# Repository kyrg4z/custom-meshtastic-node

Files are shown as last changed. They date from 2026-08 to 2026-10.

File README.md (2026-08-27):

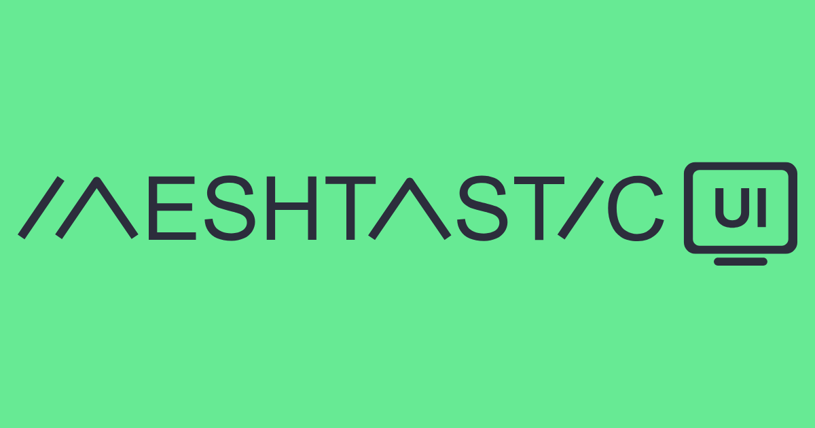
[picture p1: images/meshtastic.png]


# Custom Meshtastic/Reticulum Node 

A custom Meshtastic compatible LoRa communication device that is designed for off-grid messaging in areas where cellular/internet aren't available such as hiking trails, mountains, and forests. This device provides interface for phones to be able to send messages through long range radio through a decentralized mesh network.  

> [!NOTE]
> Read about progress status in JOURNAL.md

## Hardware Preview

Interactive KiCad viewer powered by [KiCanvas](https://kicanvas.org):

- **[Open schematic in KiCanvas](https://kicanvas.org/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)**
- **[Open PCB layout in KiCanvas](https://kicanvas.org/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)** _(board not routed yet — preview will be empty)_

A live, embedded viewer is hosted via GitHub Pages: **https://kyrg4z.github.io/custom-meshtastic-node/**

### Schematic snapshot

Schematic

<sub>Auto-exported from <code>PCB/PCB.kicad_sch</code> by <code>.githooks/pre-commit</code>. Enable it once per clone with <code>git config core.hooksPath .githooks</code>.</sub>

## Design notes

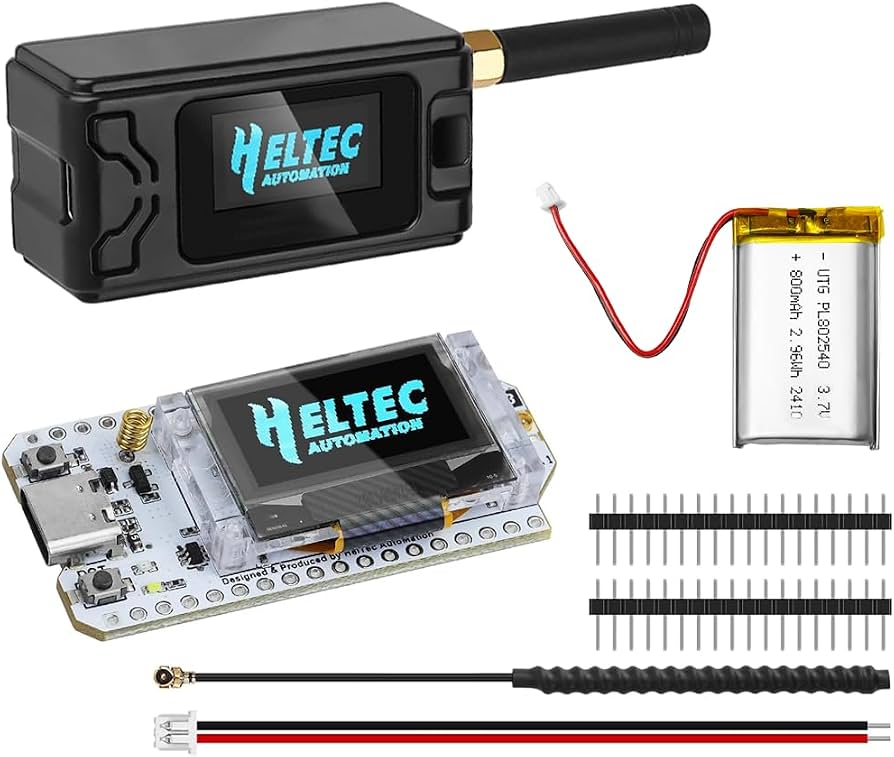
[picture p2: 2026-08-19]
images/heltec-v3.jpg

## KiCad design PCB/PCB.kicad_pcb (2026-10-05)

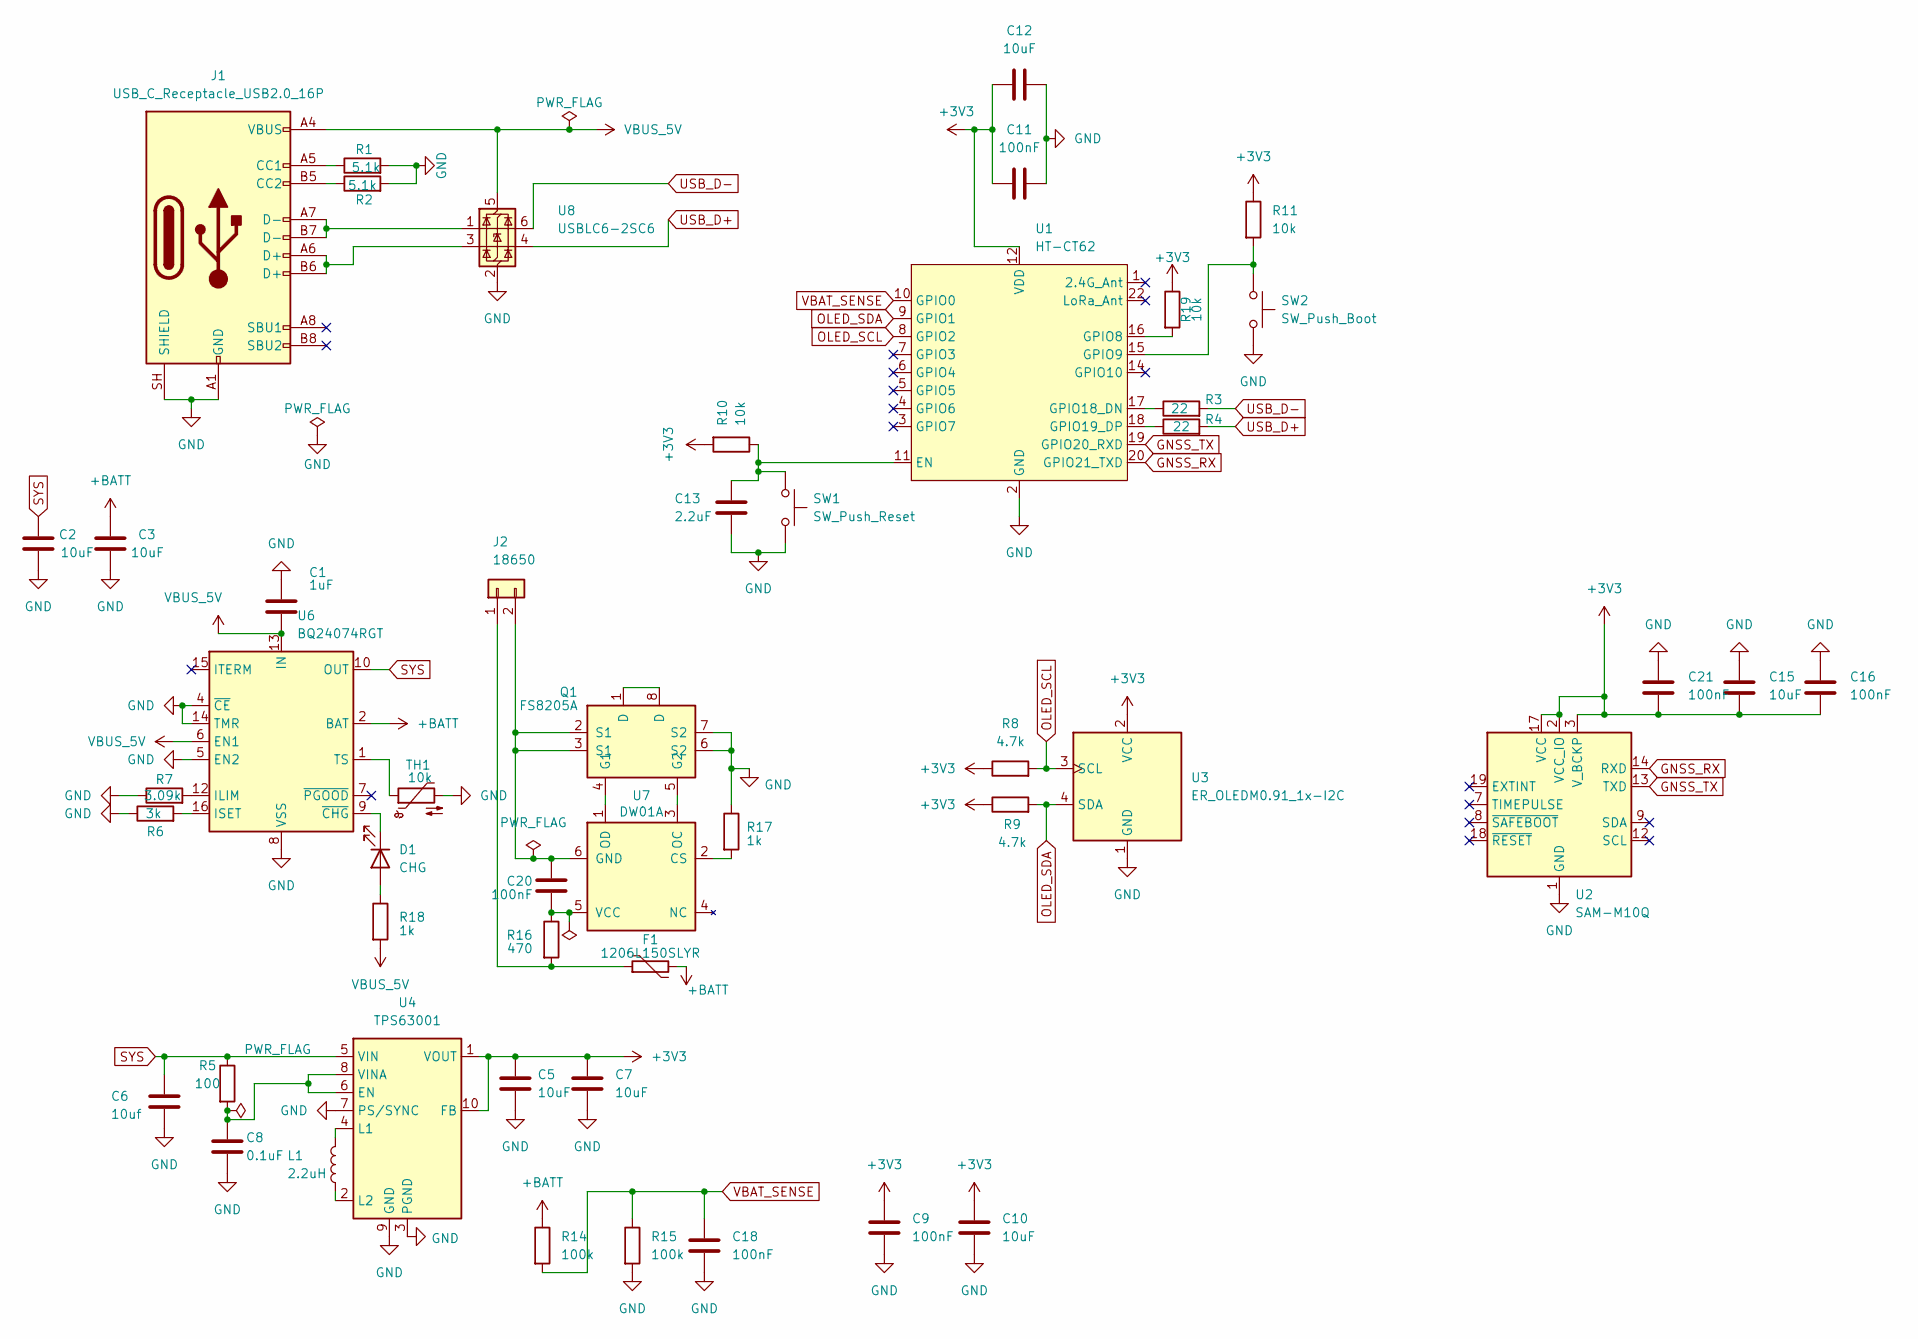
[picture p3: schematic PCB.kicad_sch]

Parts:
C1: 1uF; C_0603_1608Metric
C2, C3, C5, C7, C10, C12, C15: 10uF; C_0805_2012Metric
C6: 10uf; C_0805_2012Metric
C8: 0.1uF; C_0603_1608Metric
C9, C11, C16, C18, C20, C21: 100nF; C_0603_1608Metric
C13: 2.2uF; C_0603_1608Metric
D1: CHG; LED_0603_1608Metric
F1: 1206L150SLYR; Fuse_1206_3216Metric; MPN 1206L150SLYR
J1: USB_C_Receptacle_USB2.0_16P; USB_C_Receptacle_HRO_TYPE-C-31-M-12
J2: 18650; JST_PH_B2B-PH-K_1x02_P2.00mm_Vertical
L1: 2.2uH; L_Taiyo-Yuden_NR-30xx
Q1: FS8205A; TSSOP-8_4.4x3mm_P0.65mm; MPN FS8205A
R1, R2: 5.1k; R_0603_1608Metric
R3, R4: 22; R_0603_1608Metric
R5: 100; R_0603_1608Metric
R6: 3k; R_0603_1608Metric
R7: 3.09k; R_0603_1608Metric
R8, R9: 4.7k; R_0603_1608Metric
R10, R11, R19: 10k; R_0603_1608Metric
R14, R15: 100k; R_0603_1608Metric
R16: 470; R_0603_1608Metric
R17, R18: 1k; R_0603_1608Metric
SW1: SW_Push_Reset; SW_SPST_PTS810
SW2: SW_Push_Boot; SW_SPST_PTS810
TH1: 10k; R_0603_1608Metric
U1: HT-CT62; Heltec_HT-CT62
U2: SAM-M10Q; ublox_SAM-M8Q
U3: ER_OLEDM0.91_1x-I2C
U4: TPS63001; Texas_DRC0010J_ThermalVias
U6: BQ24074RGT; VQFN-16-1EP_3x3mm_P0.5mm_EP1.6x1.6mm
U7: DW01A; SOT-23-6; MPN DW01A
U8: USBLC6-2SC6; SOT-23-6

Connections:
+3V3: C5.1, C7.1, C9.1, C10.1, C11.2, C12.2, C15.1, C16.1, C21.1, R8.1, R9.1, R10.2, R11.1, R19.1, U1.12 (VDD), U2.2 (VCC_IO), U2.3 (V_BCKP), U2.17 (VCC), U3.2 (VCC), U4.1 (VOUT), U4.10 (FB)
+BATT: C3.1, F1.2, R14.1, U6.2 (BAT), U6.3 (BAT)
GND: C1.1, C2.2, C3.2, C5.2, C6.2, C7.2, C8.2, C9.2, C10.2, C11.1, C12.1, C13.2, C15.2, C16.2, C18.2, C21.2, J1.A1 (GND), J1.A12 (GND), J1.B1 (GND), J1.B12 (GND), J1.SH (SHIELD), Q1.6 (S2), Q1.7 (S2), R1.2, R2.2, R6.1, R7.1, R15.2, R17.1, SW1.2, SW2.2, TH1.2, U1.2 (GND), U1.13 (GND), U1.21 (GND), U2.1 (GND), U2.4 (GND), U2.5 (GND), U2.6 (GND), U2.10 (GND), U2.11 (GND), U2.15 (GND), U2.16 (GND), U2.20 (GND), U3.1 (GND), U4.3 (PGND), U4.7 (PS/SYNC), U4.9 (GND), U4.11 (PGND), U6.4 (~CE), U6.5 (EN2), U6.8 (VSS), U6.14 (TMR), U6.17 (VSS), U8.2 (GND)
GNSS_RX: U1.20 (GPIO21_TXD), U2.14 (RXD)
GNSS_TX: U1.19 (GPIO20_RXD), U2.13 (TXD)
unnamed: D1.2 (A), R18.1
unnamed: D1.1 (K), U6.9 (~CHG)
unnamed: J1.A5 (CC1), R1.1
unnamed: J1.B5 (CC2), R2.1
unnamed: J1.A6 (D+), J1.B6 (D+), U8.3 (I/O2)
unnamed: J1.A7 (D-), J1.B7 (D-), U8.1 (I/O1)
unnamed: F1.1, J2.1, R16.2
unnamed: C20.1, J2.2, Q1.2 (S1), Q1.3 (S1), U7.6 (GND)
unnamed: Q1.1 (D), Q1.8 (D)
unnamed: Q1.4 (G1), U7.1 (OD)
unnamed: Q1.5 (G2), U7.3 (OC)
unnamed: C13.1, R10.1, SW1.1, U1.11 (EN)
unnamed: R19.2, U1.16 (GPIO8)
unnamed: R11.2, SW2.1, U1.15 (GPIO9)
unnamed: R3.1, U1.17 (GPIO18_DN)
unnamed: R4.1, U1.18 (GPIO19_DP)
unnamed: C8.1, R5.2, U4.6 (EN), U4.8 (VINA)
unnamed: L1.2, U4.4 (L1)
unnamed: L1.1, U4.2 (L2)
unnamed: R7.2, U6.12 (ILIM)
unnamed: R6.2, U6.16 (ISET)
unnamed: TH1.1, U6.1 (TS)
unnamed: R17.2, U7.2 (CS)
unnamed: C20.2, R16.1, U7.5 (VCC)
OLED_SCL: R8.2, U1.8 (GPIO2), U3.3 (SCL)
OLED_SDA: R9.2, U1.9 (GPIO1), U3.4 (SDA)
SYS: C2.1, C6.1, R5.1, U4.5 (VIN), U6.10 (OUT), U6.11 (OUT)
USB_D+: R4.2, U8.4 (I/O2)
USB_D-: R3.2, U8.6 (I/O1)
VBAT_SENSE: C18.1, R14.2, R15.1, U1.10 (GPIO0)
VBUS_5V: C1.2, J1.A4 (VBUS), J1.A9 (VBUS), J1.B4 (VBUS), J1.B9 (VBUS), R18.2, U6.6 (EN1), U6.13 (IN), U8.5 (VBUS)

Board: 2 copper layers, 50 parts (0 on the bottom side), 36 nets, no tracks yet.

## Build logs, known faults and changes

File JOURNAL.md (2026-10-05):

---
title: "Meshtastic node"
github: "https://github.com/kyrg4z/custom-meshtastic-node"
description: "A custom Meshtastic LoRa communication device for off-grid messaging"
created_at: "2026-08-18"
---

# Sep-16, Sep-21 -- Oct-4th 

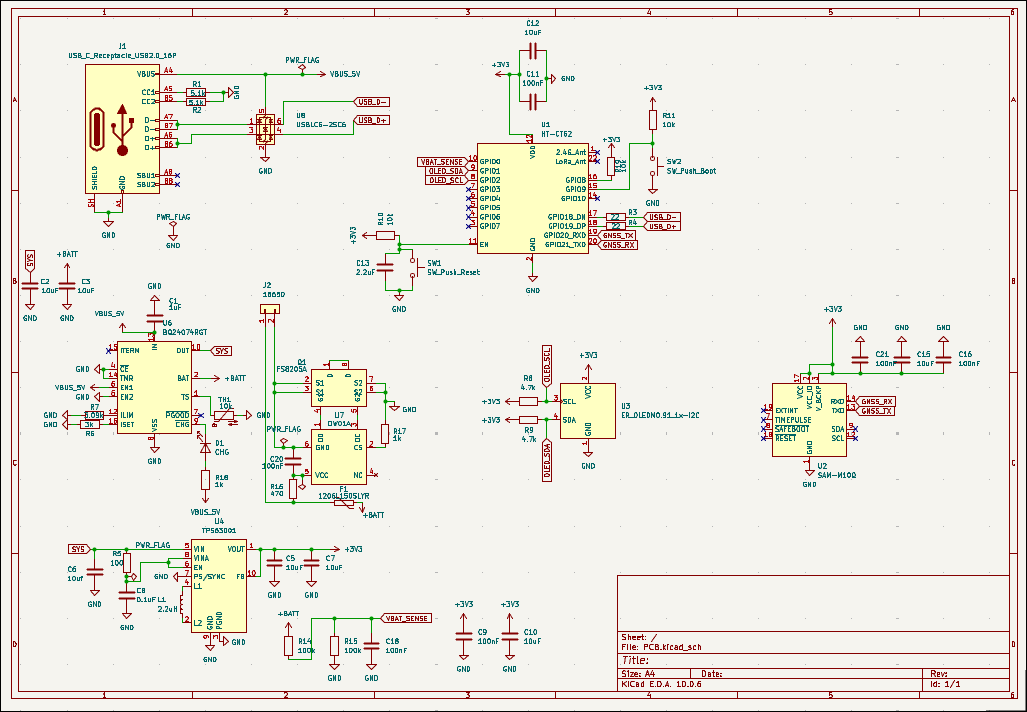
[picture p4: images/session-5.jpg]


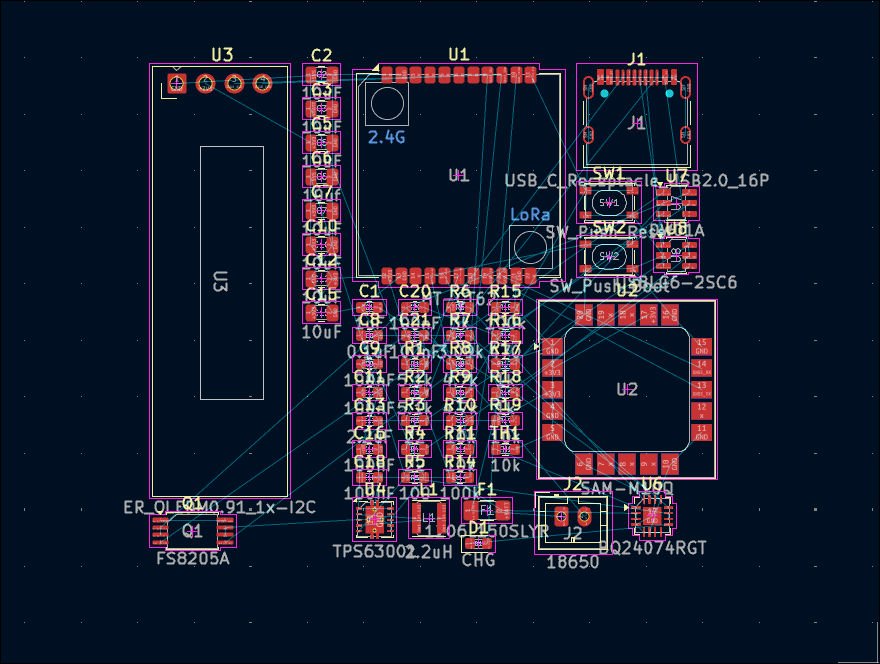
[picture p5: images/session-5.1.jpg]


In this period of time I found myself stretched apart by school assignments, tests, and community as well as other projects in need of my attention. 

So yeah, it's a bit delayed. 

I finally finished the schematic and fixed it. 

- [x] Removed the switch for the gnss module because there was no free gpio on the ht-ct62.  
- [x] Battery sense moved from GPIO3 to GPIO0
  - GPIO3 is the LoRa radio's interrupt line inside the HT-CT62, so it now has a no-connect flag.
- [x] Decided on Keystone 1042 as the holder for the battery. 
- [x] Added the esd protection for the usb-c
- [x] Added a fuse, and IC protection circuits to the charging circuit just in case 
- [x] Added an LED to the CHG on the BQ24074RGT, so it would indicate charging and stuff 
- [x] Ran the ERC, added power connector flags cause KiCad didn't like it 
- [x] Assigned footprints. 

# August 22nd 

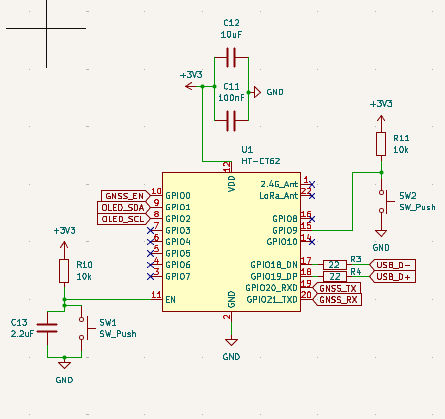
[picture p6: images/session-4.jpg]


In this session I mapped the HT-CT62 labels and power/reset buttons. 

Now I also mapped the SAM-M10Q and TPS22917DBV components. Everything looks good so far. Now I'm going to double check the pinout and schematic and add footprints for the components. 

# August 21st  

This day I continued the schematic and as I didn't have much time I just did the oled screen pretty quickly. 

I also found out that I'd need to load meshtastic firmware with certain configuration that has gps and oled pins enabled since on the ht-ct62 they aren't labeled by default. 

# August 20th

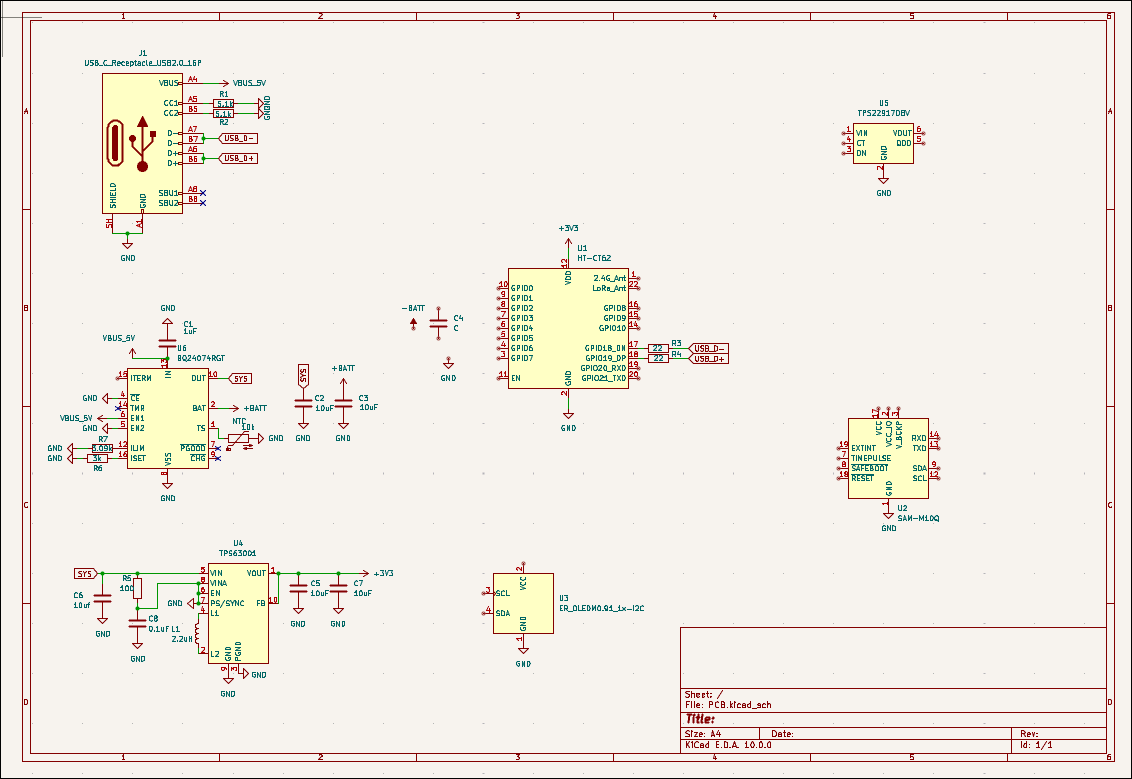
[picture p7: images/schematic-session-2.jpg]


Today I decided to choose a gps/gnss module or a chip. 
Turns out that standard gnss has precision of 3-10m so it is what I need 

Turns out that there are bunch of sattelite systems.

Reading a bit I chose the SAM-M10Q module since it is a low-cost gnss module which incorporates built-in chip, circuitry, and antenna.

Then I started reading datasheet of ht-ct62 and then sx1262. 

Also I then checked the firmware for ht-ct62. Thank God it was available. 

For the display I chose ssd1306 since it is a low-cost OLED display module. 

Since I do want to have a 18650 battery power supply, I need to have a buck boost converter that can step up and step down the voltage.

So the whole thing would be something like this: 

```mermaid
flowchart TD
    USB["USB-C <br/> 5 V"] --> CHG["BQ24074RGTR <br/> charger"]
    BAT["18650 battery<br/> 3.0–4.2 V"] --> CHG
    CHG --> SYS["SYS <br/> 3.0–4.5 V"]
    SYS --> BB["TPS63001 <br/> buck-boost converter"]
    BB --> RAIL["3.3 V rail"]
    RAIL --> MAIN["HT-CT62 + OLED"]
    RAIL --> LOAD["TPS22917 <br/> load switch"]
    LOAD --> GPS["SAM-M10Q <br/> GPS module"]
```

I then set up the usb_c and charging IC bq24074gtr. 

For setting up the charging IC I followed this logic 
EN1 and EN2 configuration

EN2 = 0
EN1 = 1

Which places the charger in USB 500 mA input-limit mode:

EN2	EN1	Mode
0	0	100 mA USB
0	1	500 mA USB
1	0	Current set by ILIM resistor
1	1	Standby

For the buck boost converter it has to be pretty much like datasheet except for PS/SYNC. 

It controls the operating mode

- PS/SYNC state	Mode
- LOW/GND	Power-save mode enabled
- HIGH	Power-save disabled; forced fixed-frequency operation
- Clock signal	Synchronizes switching to an external clock

## So in this session I:
- Researched additional components
- Chose to add SAM-M10Q GPS module, SSD1306 oled, BQ24074RGTR battery charger, and TPS63001 buck-boost converter 
- Read the datasheets for each component
- Started the schematic

## Next steps:
- Continue schematic 
- Review the schematic and make any necessary changes

# August 18th

This is honestly my first journal entry. First hackclub project. And I genuinely forgot to record a lapse.

I started my day by researching what kind of hardware Meshtastic nodes generally use.

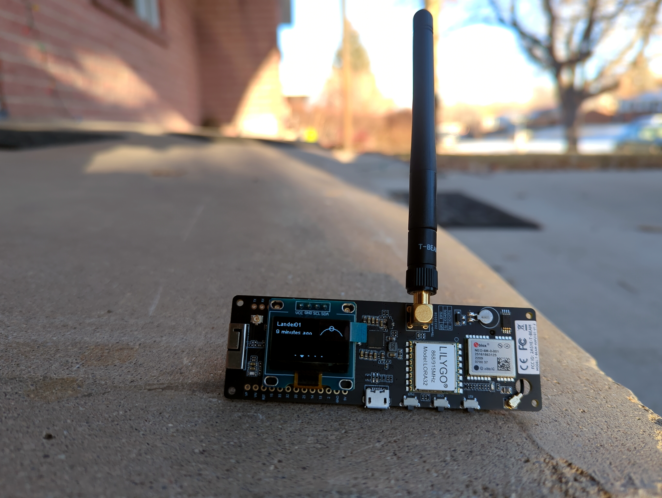
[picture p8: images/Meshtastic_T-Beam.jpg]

I looked at bunch of brands like **heltec, lilygo, and seed studio.**

Each board usually has

* **microcontroller** (built-in wifi or bluetooth or both)
* **LoRa module** (such as sx1262 or sx1278)
* **antenna connection and antenna**
* **USB-C**
* **display**

and it usually runs on a **battery or solar power.**

Some nodes are used for tracking, so they have **GPS modules.**

Some nodes are used for monitoring, so they have **sensors for temperature, humidity, etc.**

For my node I decided it to be an **off-grid messaging device** so I would like it to have gps and be pretty low-power but also being able to be charged via USB-C from a powerbank.

Now coming to the choice of parts I figured there are **2 main ways to go:**

1. **Use a bare chip or SoC (system on a chip)**

* **ESP32-C3** - less powerful than S3, single core risc-v (wifi, bluetooth)

  * cheap and simple, less pins too
* **ESP32-S3** - more powerful than C3, dual core xtensa lx7 (wifi, bluetooth)

  * more expensive, more pins
* **nRF52840** (bluetooth)

  * really low power, but no wifi

2. **Use a module (pre-built with a SoC and other components)**

* **ESP32-C3-WROOM-1**
* **ESP32-C3-MINI-1**
* **ESP32-S3-MINI-1U**
* **[HT-CT62](https://meshtastic.org/docs/hardware/devices/heltec-automation/ht62/)** (built-in esp32-c3 + sx1262 lora transciever)

  * not a lot of pins but seems like a really good fit
* **nRF52840 module like Raytac MDBT50Q**

The thing is if I go with first option, I would need to add a lot of things myself like **decoupling, crystals, rf antenna ciruitry, and layout around the chip** which is not ideal since I want to build a quick prototype and it's basically my first RF project.

So really I should just decide between choosing **esp32-c3-wroom-1 or ht-ct62 (or nRF52840 module).**

I think for now **ht-ct62 is the best option** since it has a built-in esp32-c3 and sx1262 lora transciever, and is relatively cheap.

Just for the sake of learning I looked into **LoRa radios and modules.**

* **SX1262**
* **SX1276**
* **SX1278**
* **RFM95**

so **127*** are the older gen transceivers and **126*** are the newer gen transceivers.

and **RFM95** is a module that uses older sx1276 chip.

Since I'm going with **HT-CT62**, I don't need to add any of thse because ht-ct62 already has a built-in sx1262 lora module.

Now Lora radios use different frequencies and I figured that **US/Canada uses 915 MHz** which is part of the **license-free ISM band.**

Turns out there are many ways to classify radio communication.

By frequency like **high frequency (HF), medium frequency (MF), or low frequency (LF).**

By radio services like **amateur radio, general mobile radio service, family radio service, and citizens band.**

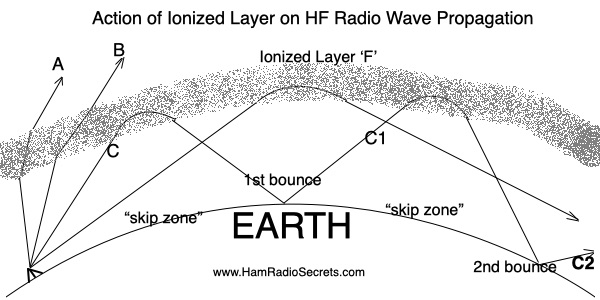
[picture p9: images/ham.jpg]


And it's crazy that amateur radio can travel thousands of miles without satellites, repeaters, intermediate nodes or cellular towers. This can happen because the wave is launched at an angle and when it hits the **ionosphere** it is refracted back to Earth instead of only traveling line of sight.

Going a bit further into research I found a **reticulum network** - a pretty interesting project which is a secure decentralized communication network which allows
creation of independent local and wide area networks. Pretty cool!

Back to the project. I decided to add to the board **standard usb-c, reset button, antenna, gps, and maybe oled.**

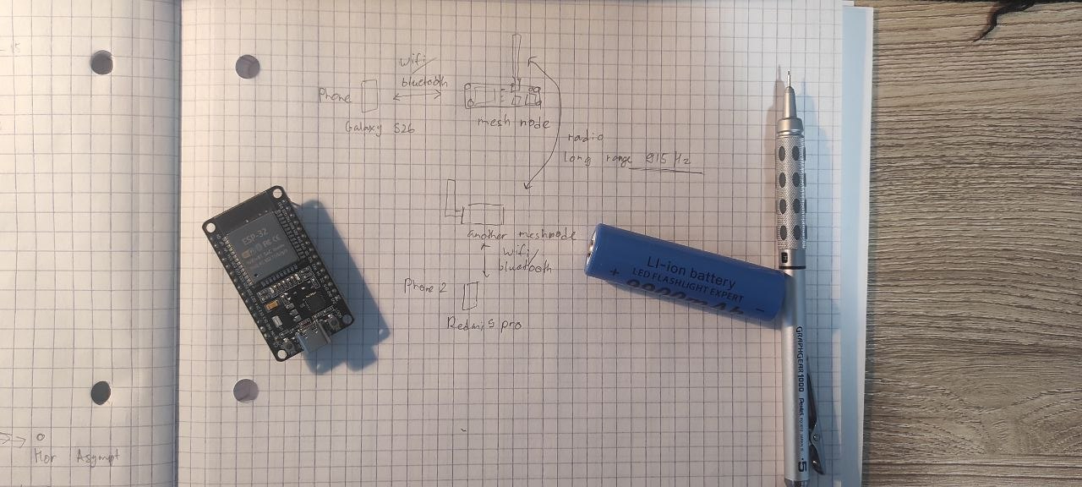
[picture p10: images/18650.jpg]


Oh and also I want to add **18650 battery** since I want to run the board on battery power and not just usb power.

## So in this session I:

* researched about **mcu vs module**
* learned about **reticulum network**
* read about different **radio transceivers and modules**
* discovered for myself a lot of interesting things about **radio communication**
* decided to use **HT-CT62 as my radio module for the project**

## Next steps:

* read **ht-ct62 datasheet**
* find and study the **HT-CT62 reference schematic**
* figure out which **gpio pins** to use and which are available
* research about **usb power circuitry and 18650 implementation**
* decide if I want an **OLED display**
* start the **KiCad schematic and PCB design**

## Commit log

2026-08-19 1st journal, README added, planning
    [PCB.kicad_pcb, PCB.kicad_sch]
2026-08-21 added journal entry #2, started schematic
    [PCB.kicad_sch]
2026-08-22 added oled screen
    [PCB.kicad_sch]
2026-08-22 mapped the ht-ct62
    [PCB.kicad_sch]
2026-08-22 mapped the gps and load switch
    [PCB.kicad_sch]
2026-08-23 fixing schemating
    [PCB.kicad_sch]
2026-08-27 schematic fix attempts
    [PCB.kicad_sch]
2026-09-22 fixing parts of schematic
    [PCB.kicad_sch]
2026-10-05 finishing schematic, assigning footprints
    [PCB.kicad_pcb, PCB.kicad_sch]
2026-10-11 gerbers, firmware, and prod
2026-10-14 Fixed Bom again, made the oled DNP
2026-10-14 Update PCB snapshot [skip ci]
2026-10-15 Add 3D models for every component and re-export full STEP
    - J1, U4, U6, L1: point to stock KiCad models of equivalent packages
    (the referenced HRO/DRC0010J/VQFN/NR-30xx models are not in KiCad's library)
    - U1, U2: generated dimensioned stand-ins (CadQuery) in PCB/3dmodels
    - U3: attach oled.stp plus a generated carrier board/header stand-in
    - Re-export PRODUCTION/PCB.step with no missing models
    - README: 3D Model section with top/bottom/iso renders, enclosure note
    Only 3D model references changed in PCB.kicad_pcb; copper, pads and
    gerbers are untouched.
2026-10-15 Replace OLED stand-in with a detailed ER-OLEDM0.91-1 module model
    Single model for U3: carrier PCB with plated holes and pin labels,
    1x4 header with soldered pins, two-layer glass with lit active area,
    driver IC and FPC wrapped round the far edge. Re-exported STEP and
    README renders.
2026-10-19 added BOM for stardance, fixed the j3, made it a connector, and re-exported gerbers
